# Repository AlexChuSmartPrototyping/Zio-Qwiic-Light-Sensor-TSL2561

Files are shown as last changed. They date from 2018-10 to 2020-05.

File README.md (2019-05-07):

# Zio Qwiic Light Sensor (TSL2561)

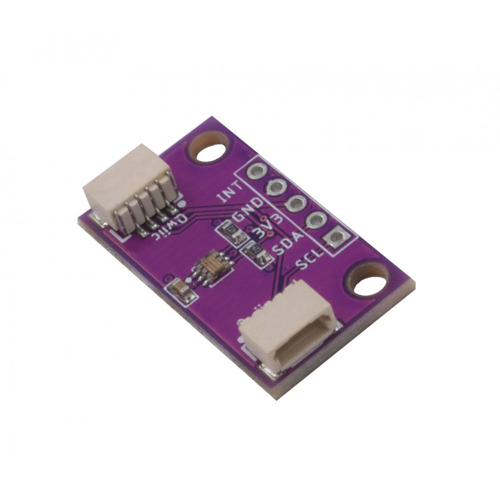
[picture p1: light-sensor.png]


> This product can be available for purchase [here](https://www.smart-prototyping.com/Zio-Qwiic-Light-Sensor-TSL2561).

#### Description

This inexpensive precision light sensor is, although compact in size, is robust enough to output the exact luminance rate for visible light (Approximates Human Eye Response), invisible light (IR), and full light (both visible and invisible light) from up to 0.1 - 40,000+ lux on the fly! 

With [Qwiic](https://www.smart-prototyping.com/Qwiic.html) installed you can effortlessly prototype your projects without soldering and complicated wiring. We also added I2C pins for connecting to modules outside the qwiic domain.

Especially reliable for projects and applications involving Street light controlling system, monitoring luminosity of the living environment, or simply doing research on light brightness. 

All in all, if you need a light sensor in a project, this is definitely the right choice!

#### Specification

* Dynamic range (Lux): 0.1 to 40,000 Lux
* Voltage range: 2.7-3.6V
* Interface: I2C
* I2C Address: 0x39 (Default), 0x29, 0x49, selectable with jumpers
* Module dimension: 14.4x 25.4mm
* Weight: 1.3g

#### Links

* [PCB Source file and Gerber file](https://github.com/ZIOCC/Zio-Qwiic-Light-Sensor-TSL2561)
* [PCB Schematic](https://github.com/ZIOCC/Zio-Qwiic-Light-Sensor-TSL2561/blob/master/Zio%20Qwiic%20Light%20Sensor%20TSL2561%20Schematic%20PDF.pdf)
* [Demo Code and library](https://github.com/adafruit/TSL2561-Arduino-Library)

> ###### About Zio
> Zio is a new line of open sourced, compact, and grid layout boards, fully integrated for Arduino and Qwiic ecosystem. Designed ideally for wearables, robotics, small-space limitations or other on the go projects. Check out other awesome Zio products [here](https://www.smart-prototyping.com/Zio).

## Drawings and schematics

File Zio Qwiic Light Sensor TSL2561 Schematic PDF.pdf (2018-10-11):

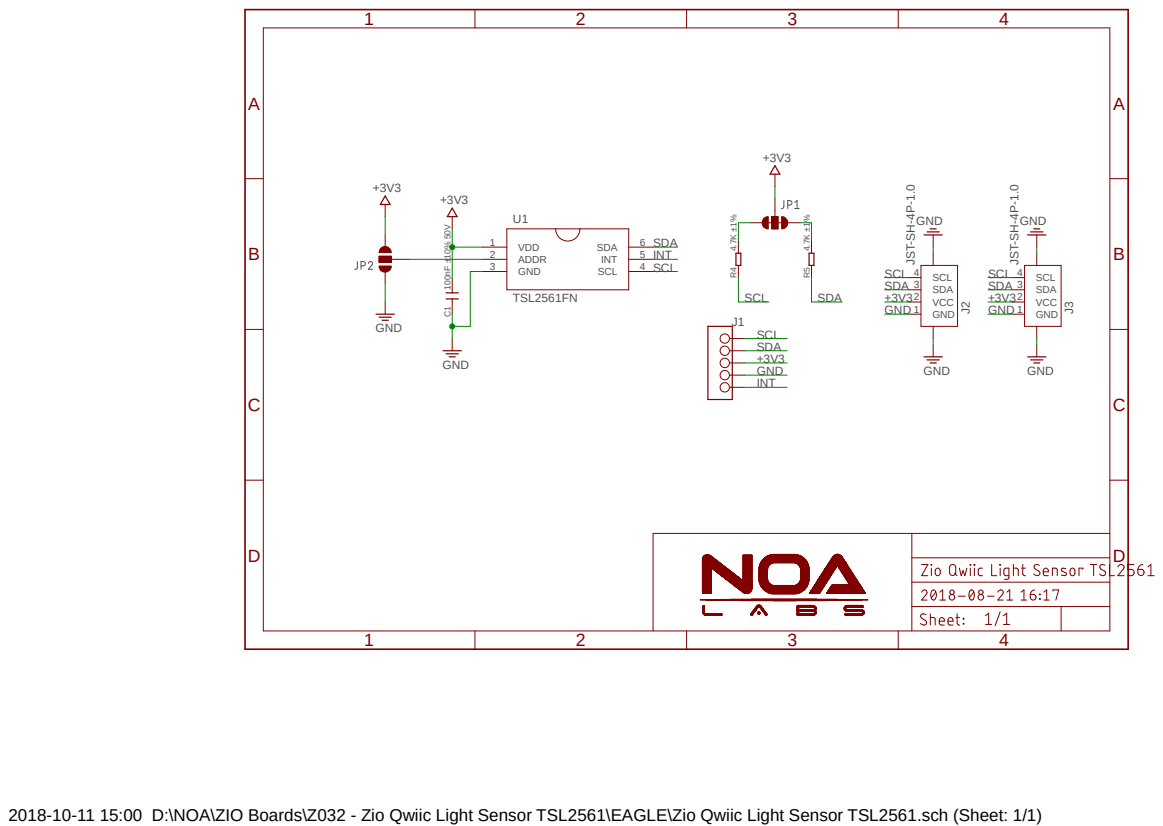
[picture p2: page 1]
TSL2561FN ¹⁰⁰nF ±10% ⁵⁰V; GND; GND 4.7K ±1%; VDD 1 ADDR 2; GND 3; SCL; INT; SDA; GND 1; VCC 2; SDA 3; SCL 4; J3 JST⁻SH⁻⁴P⁻¹.0; J2 JST⁻SH⁻⁴P⁻¹.0 R⁴

2018-10-11 15:00 D:\NOA\ZIO Boards\Z032 - Zio Qwiic Light Sensor TSL2561\EAGLE\Zio Qwiic Light Sensor TSL2561.sch (Sheet: 1/1)

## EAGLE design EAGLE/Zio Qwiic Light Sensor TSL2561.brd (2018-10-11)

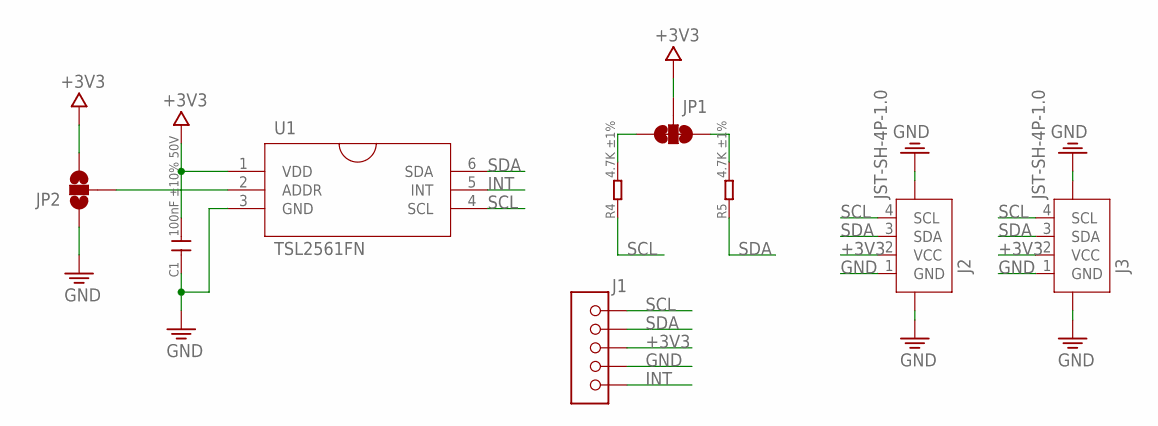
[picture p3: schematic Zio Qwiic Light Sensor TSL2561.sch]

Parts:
C1: 100nF ±10% 50V; C0603
J1: HEADER-5P-2.54; 5P-2.54
J2, J3: JST-SH-4P-1.0; JST-SH-4P
JP1: SMT-JUMPER_3_2-NC_TRACE
JP2: JUMPER-SMT_3_2-NC_PASTE_NOCREM; SMT-JUMPER_3_2-NC_PASTE_SILK_NOCREM
R4, R5: 4.7K ±1%; R0603
U1: TSL2561FN; FN6

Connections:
+3V3: C1.2, J1.3, J2.2 (VCC), J3.2 (VCC), JP1.2, JP2.3, U1.1 (VDD)
GND: C1.1, J1.4, J2.1 (GND), J2.NC1 (5), J2.NC2 (6), J3.1 (GND), J3.NC1 (5), J3.NC2 (6), JP2.1, U1.3 (GND)
INT: J1.5, U1.5 (INT)
unnamed: JP2.2, U1.2 (ADDR)
unnamed: JP1.3, R4.2
unnamed: JP1.1, R5.2
SCL: J1.1, J2.4 (SCL), J3.4 (SCL), R4.1, U1.4 (SCL)
SDA: J1.2, J2.3 (SDA), J3.3 (SDA), R5.1, U1.6 (SDA)

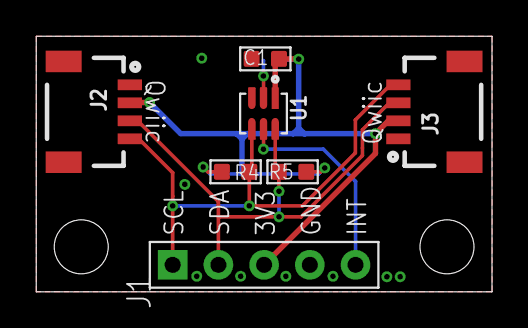
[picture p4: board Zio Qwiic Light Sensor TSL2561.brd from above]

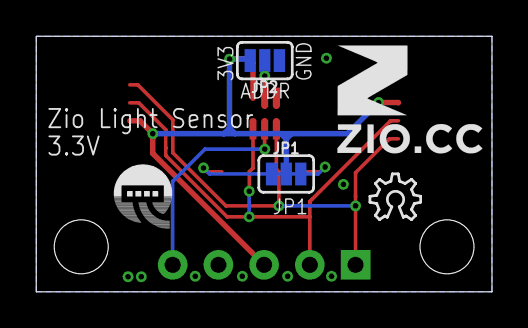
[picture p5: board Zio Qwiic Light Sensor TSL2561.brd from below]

Board: 2 copper layers, 25.3 x 14.2 mm, 12 parts (5 on the bottom side), 8 nets.

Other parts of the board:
U$4: 6MM
U$5: QWIIC-LOGO-BASIC
U$6: OSHW_6X100_NOTEXT

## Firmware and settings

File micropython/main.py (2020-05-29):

"""
Demo code for Qwiic Light Sensor TSL2561, tested on pyboard
Auther: Alex Chu
Website: www.smart-prototyping.com
Email: shop@smart-prototyping.com
Qwiic Light Sensor TSL2561 product link: https://www.smart-prototyping.com/Zio-Qwiic-Light-Sensor-TSL2561
Display product link: https://www.smart-prototyping.com/Zio-OLED-Display-0-91-in-128-32-Qwiic.html
Library: https://github.com/adafruit/micropython-adafruit-tsl2561
"""

from machine import Pin,I2C
import tsl2561
from ssd1306 import SSD1306_I2C

i2c = I2C(sda=Pin("Y10"), scl=Pin("Y9"))
oled = SSD1306_I2C(128, 32, i2c, addr=0x3c)

light = tsl2561.TSL2561(i2c=i2c,address=0x39)

pyb.delay(100)
light.active(True)
pyb.delay(500)

while True:
    value = round(light.read(),2)
    oled.fill(0)
    oled.text("luminosity is:", 0, 0)
    oled.text(str(value) + " lux", 0, 20)
    pyb.delay(10)
    oled.show()
    pyb.delay(100)

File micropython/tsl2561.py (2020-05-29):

# https://github.com/adafruit/micropython-adafruit-tsl2561

import time
import ustruct


_COMMAND_BIT = const(0x80)
_WORD_BIT = const(0x20)

_REGISTER_CONTROL = const(0x00)
_REGISTER_TIMING = const(0x01)
_REGISTER_THRESHHOLD_MIN = const(0x02)
_REGISTER_THRESHHOLD_MAX = const(0x04)
_REGISTER_INTERRUPT = const(0x06)
_REGISTER_ID = const(0x0A)
_REGISTER_CHANNEL0 = const(0x0C)
_REGISTER_CHANNEL1 = const(0x0E)

_CONTROL_POWERON = const(0x03)
_CONTROL_POWEROFF = const(0x00)

_INTERRUPT_NONE = const(0x00)
_INTERRUPT_LEVEL = const(0x10)

_INTEGRATION_TIME = {
#  time     hex     wait    clip    min     max     scale
    13:     (0x00,  15,     4900,   100,    4850,   0x7517),
    101:    (0x01,  120,    37000,  200,    36000,  0x0FE7),
    402:    (0x02,  450,    65000,  500,    63000,  1 << 10),
    0:      (0x03,  0,      0,      0,      0,      0),
}


class TSL2561:
    _LUX_SCALE = (
    #       K       B       M
        (0x0040, 0x01f2, 0x01be),
        (0x0080, 0x0214, 0x02d1),
        (0x00c0, 0x023f, 0x037b),
        (0x0100, 0x0270, 0x03fe),
        (0x0138, 0x016f, 0x01fc),
        (0x019a, 0x00d2, 0x00fb),
        (0x029a, 0x0018, 0x0012),
    )

    def __init__(self, i2c, address=0x39):
        self.i2c = i2c
        self.address = address
        sensor_id = self.sensor_id()
        if not sensor_id & 0x10:
            raise RuntimeError("bad sensor id 0x{:x}".format(sensor_id))
        self._active = False
        self._gain = 1
        self._integration_time = 13
        self._update_gain_and_time()

    def _register16(self, register, value=None):
        register |= _COMMAND_BIT | _WORD_BIT
        if value is None:
            data = self.i2c.readfrom_mem(self.address, register, 2)
            return ustruct.unpack('<H', data)[0]
        data = ustruct.pack('<H', value)
        self.i2c.writeto_mem(self.address, register, data)

    def _register8(self, register, value=None):
        register |= _COMMAND_BIT
        if value is None:
            return self.i2c.readfrom_mem(self.address, register, 1)[0]
        data = ustruct.pack('<B', value)
        self.i2c.writeto_mem(self.address, register, data)

    def active(self, value=None):
        if value is None:
            return self._active
        value = bool(value)
        if value != self._active:
            self._active = value
            self._register8(_REGISTER_CONTROL,
                _CONTROL_POWERON if value else _CONTROL_POWEROFF)

    def gain(self, value=None):
        if value is None:
            return self._gain
        if value not in (1, 16):
            raise ValueError("gain must be either 1x or 16x")
        self._gain = value
        self._update_gain_and_time()

    def integration_time(self, value=None):
        if value is None:
            return self._integration_time
        if value not in _INTEGRATION_TIME:
            raise ValueError("integration time must be 0, 13ms, 101ms or 402ms")
        self._integration_time = value
        self._update_gain_and_time()

    def _update_gain_and_time(self):
        was_active = self.active()
        self.active(True)
        self._register8(_REGISTER_TIMING,
            _INTEGRATION_TIME[self._integration_time][0] |
            {1: 0x00, 16: 0x10}[self._gain]);
        self.active(was_active)

    def sensor_id(self):
        return self._register8(_REGISTER_ID)

    def _read(self):
        was_active = self.active()
        self.active(True)
        if not was_active:
            # if the sensor was off, wait for measurement
            time.sleep_ms(_INTEGRATION_TIME[self._integration_time][1])
        broadband = self._register16(_REGISTER_CHANNEL0)
        ir = self._register16(_REGISTER_CHANNEL1)
        self.active(was_active)
        return broadband, ir

    def _lux(self, channels):
        if self._integration_time == 0:
            raise ValueError(
                "can't calculate lux with manual integration time")
        broadband, ir = channels
        clip = _INTEGRATION_TIME[self._integration_time][2]
        if broadband > clip or ir > clip:
            raise ValueError("sensor saturated")
        scale = _INTEGRATION_TIME[self._integration_time][5] / self._gain
        channel0 = (broadband * scale) / 1024
        channel1 = (ir * scale) / 1024
        ratio = (((channel1 * 1024) / channel0 if channel0 else 0) + 1) / 2
        for k, b, m in self._LUX_SCALE:
            if ratio <= k:
                break
        else:
            b = 0
            m = 0
        return (max(0, channel0 * b - channel1 * m) + 8192) / 16384

    def read(self, autogain=False, raw=False):
        broadband, ir = self._read()
        if autogain:
            if self._integration_time == 0:
                raise ValueError(
                    "can't do autogain with manual integration time")
            new_gain = self._gain
            if broadband < _INTEGRATION_TIME[self._integration_time][3]:
                new_gain = 16
            elif broadband > _INTEGRATION_TIME[self._integration_time][4]:
                new_gain = 1
            if new_gain != self._gain:
                self.gain(new_gain)
                broadband, ir = self._read()
        if raw:
            return broadband, ir
        return self._lux((broadband, ir))

    def threshold(self, cycles=None, min_value=None, max_value=None):
        if min_value is None and max_value is None and cycles is None:
            min_value = self._register16(_REGISTER_THRESHHOLD_MIN)
            max_value = self._register16(_REGISTER_THRESHHOLD_MAX)
            cycles = self._register8(_REGISTER_INTERRUPT)
            if not cycles & _INTERRUPT_LEVEL:
                cycles = -1
            else:
                cycles &= 0x0f
            return cycles, min_value, max_value
        was_active = self.active()
        self.active(True)
        if min_value is not None:
            self._register16(_REGISTER_THRESHHOLD_MIN, int(min_value))
        if max_value is not None:
            self._register16(_REGISTER_THRESHHOLD_MAX, int(max_value))
        if cycles is not None:
            if cycles == -1:
                self._register8(_REGISTER_INTERRUPT, _INTERRUPT_NONE)
            else:
                self._register8(_REGISTER_INTERRUPT,
                    min(15, max(0, int(cycles))) | _INTERRUPT_LEVEL)
        self.active(was_active)

    def interrupt(self, value):
        if value or value is None:
            raise ValueError("can only clear the interrupt")
        self.i2c.writeto(self.address, b'\x40')


# Those packages are identical.
TSL2561T = TSL2561
TSL2561FN = TSL2561
TSL2561CL = TSL2561


class TSL2561CS(TSL2561):
    # This package has different lux scale.
    _LUX_SCALE = (
    #       K       B       M
        (0x0043, 0x0204, 0x01ad),
        (0x0085, 0x0228, 0x02c1),
        (0x00c8, 0x0253, 0x0363),
        (0x010a, 0x0282, 0x03df),
        (0x014d, 0x0177, 0x01dd),
        (0x019a, 0x0101, 0x0127),
        (0x029a, 0x0037, 0x002b),
    )
